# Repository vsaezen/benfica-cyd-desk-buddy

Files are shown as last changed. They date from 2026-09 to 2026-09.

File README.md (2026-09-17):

# Benfica CYD Desk Buddy

Proyecto de sobremesa para la pantalla táctil **Freenove FNK0114L / E32R32P de
3,2 pulgadas**. Reúne una interfaz inspirada en el Benfica, audio local,
información deportiva por Wi-Fi y una carcasa imprimible en 3D.

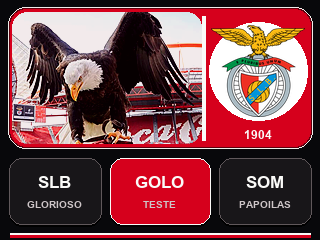
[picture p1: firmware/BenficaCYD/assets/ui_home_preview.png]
Interfaz principal


## Funciones

- Interfaz táctil de cuatro páginas con transiciones horizontales.
- Escudo, águila animada, `SLB GLORIOSO` y `PAPOILAS SALTITANTES`.
- Próximo partido, marcador, goleadores y clasificación portuguesa.
- Detección de partidos de Liga, Champions y otras competiciones.
- Himno con letra sincronizada.
- Reproducción autónoma desde microSD y altavoz de 8 ohmios.
- Configuración del Wi-Fi desde el móvil, sin guardar contraseñas en el código.
- Carcasa Rev. G para imprimir en una Bambu Lab A1 u otra impresora FDM.

## Antes de empezar

Este firmware está ajustado para el modelo exacto `FNK0114L_3P2` con ESP32
clásico, pantalla ST7789 de 240x320 y el amplificador integrado de esa placa. No
se debe cargar sin adaptar los pines en otras variantes de CYD.

Consulta primero:

1. [Instalación y copia en otra CYD](docs/INSTALACION.md)
2. [Esquema de conexiones](docs/CONEXIONES.md)
3. [Preparación de la microSD](sdcard/README.md)
4. [Impresión y montaje de la carcasa](hardware/enclosure/README.md)

## Instalación resumida

1. Formatea una microSD como FAT32 y copia en su raíz la carpeta
   `sdcard/Benfica`.
2. Instala ESP32 Arduino **2.0.11**, ArduinoJson **7.4.2**, ESP8266Audio
   **2.0.0** y la edición de `TFT_eSPI` suministrada por Freenove.
3. Comprueba que `TFT_eSPI` tiene seleccionado
   `FNK0114L_3P2_240x320_ST7789`. En `extras/TFT_eSPI_Setups` se conserva la
   configuración exacta utilizada en este proyecto.
4. Abre `firmware/BenficaCYD/BenficaCYD.ino` en Arduino IDE.
5. Selecciona `ESP32 Dev Module` y la partición
   `Huge APP (3MB No OTA/1MB SPIFFS)`.
6. Sube el programa por USB.
7. En el primer inicio, conéctate desde el móvil a `Benfica-CYD-Setup`, abre
   `http://192.168.4.1` y configura el Wi-Fi de casa.

## Estructura del repositorio

```text
firmware/BenficaCYD/     Sketch, imágenes integradas, fuente y herramientas
sdcard/Benfica/          Archivos que deben copiarse a la tarjeta FAT32
hardware/enclosure/      STL, proyectos 3MF, Blender y scripts de la carcasa
docs/                    Instalación detallada y conexiones
extras/                  Configuración de TFT_eSPI usada durante el desarrollo
```

## Estado de la información deportiva

La interfaz y el audio funcionan sin ordenador. Los últimos datos válidos se
guardan en el ESP32 y se muestran inmediatamente al encenderlo. La consulta
directa a los servidores públicos de ESPN no es una API oficial para este
proyecto y puede responder de manera intermitente, especialmente al descargar
la clasificación completa. El firmware conserva la caché anterior cuando una
consulta falla.

Una CYD recién programada no contiene esa caché: mostrará `A ATUALIZAR` hasta
que consiga una primera actualización válida. Para fabricar varias unidades y
garantizar actualizaciones estables se recomienda añadir en el futuro un
pequeño intermediario web con una respuesta JSON reducida.

## Licencias y marcas

El código y la documentación propios se publican bajo la licencia MIT incluida
en este repositorio. La fuente Graduate conserva su licencia OFL.

Este es un proyecto de aficionados, no oficial y no afiliado con Sport Lisboa e
Benfica, Freenove ni ESPN. Sus nombres, escudos, marcas, imágenes, canciones y
grabaciones pertenecen a sus respectivos titulares y no quedan cubiertos por la
licencia MIT. Antes de redistribuir o vender una unidad, sustituye cualquier
recurso para el que no tengas permiso de distribución.

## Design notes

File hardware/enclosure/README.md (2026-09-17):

# Carcasa Rev. G

Carcasa de sobremesa para la Freenove `FNK0114L_3P2` / `E32R32P`, un altavoz
redondo de 45x12 mm y una extensión USB-C trasera.

## Archivo recomendado

Para Bambu Lab A1 con boquilla de 0,4 mm abre:

```text
3mf/Benfica_CYD_Desk_Buddy_Freenove_3P2_REV_G_ALL_IN_ONE_A1_PLATE.3mf
```

No utilices `Auto arrange`: las piezas ya están colocadas en la cama. Revisa el
perfil antes de imprimir; se recomienda capa de 0,20 mm, cuatro perímetros y
20 % de relleno gyroid.

También están separados:

- `3mf/...REV_G_LCD_ALIGNED_EASY_CLOSE.3mf`: cuerpo y tapa.
- `3mf/...REV_G_PREMIUM_TRIMS.3mf`: embellecedores en segundo color.
- `stl/`: cinco piezas individuales para otros laminadores.
- `source/`: archivo Blender y generadores usados para modificar el diseño.

## Montaje

1. Introduce la placa desde la parte trasera y apóyala contra el marco frontal.
2. Alinea sus cuatro taladros con los soportes del cuerpo.
3. Fíjala con cuatro M3, arandelas y tuercas, apretando suavemente en cruz.
4. Comprueba pantalla y táctil antes de pegar el embellecedor frontal.
5. Conecta el altavoz, introduce la microSD y organiza el cable USB-C.
6. Cierra la tapa trasera y fíjala con cuatro M3.
7. Pega los embellecedores con cinta fina 3M o microgotas de cianoacrilato en
   gel, nunca sobre el cristal.

La abertura del frontal está ajustada de forma asimétrica a la unidad física
medida durante el prototipado. Las tolerancias pueden variar ligeramente entre
impresoras; limpia rebabas y elephant foot antes de forzar una pieza.

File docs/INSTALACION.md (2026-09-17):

# Instalación en una CYD nueva

## 1. Hardware compatible

La configuración verificada corresponde a:

- Freenove `FNK0114L_3P2` / `E32R32P`.
- ESP32 clásico de doble núcleo.
- Pantalla IPS táctil ST7789, 240x320 píxeles.
- Ranura microSD y amplificador analógico integrados.
- Altavoz pasivo de 8 ohmios y 1 W.

Si el modelo serigrafiado es distinto, no lo programes con estos pines sin
comparar antes el esquema del fabricante.

## 2. Preparar Arduino IDE

Configuración usada para compilar la versión probada:

| Componente | Versión/configuración |
|---|---|
| ESP32 Arduino | 2.0.11 |
| Placa | ESP32 Dev Module |
| Upload Speed | 460800 |
| Partition Scheme | Huge APP (3MB No OTA/1MB SPIFFS) |
| ArduinoJson | 7.4.2 |
| ESP8266Audio | 2.0.0 |
| TFT_eSPI Freenove | 2.5.43 |

Instala ArduinoJson y ESP8266Audio desde el gestor de bibliotecas. Para la
pantalla, instala la copia de TFT_eSPI incluida en el tutorial de Freenove para
esta placa. En `User_Setup_Select.h` debe quedar activa esta selección:

```cpp
#define FNK0114L_3P2_240x320_ST7789
```

Las demás selecciones Freenove del mismo bloque deben estar comentadas. El
archivo exacto de configuración usado está en:

```text
extras/TFT_eSPI_Setups/FNK0114L_3.2_240x320_ST7789.h
```

## 3. Preparar la microSD

1. Formatea la tarjeta como FAT32.
2. Copia la carpeta `sdcard/Benfica` completa a la raíz.
3. La ruta final debe ser `/Benfica/goal.mp3`, no
   `/sdcard/Benfica/goal.mp3` ni `/Benfica/Benfica/goal.mp3`.
4. Inserta la tarjeta con la placa apagada.

## 4. Subir el firmware

1. Conserva juntos `BenficaCYD.ino`, `BenficaAssets.h` y `BenficaFont.h` dentro
   de la carpeta `firmware/BenficaCYD`.
2. Abre `BenficaCYD.ino`.
3. Selecciona la placa, partición y puerto USB correctos.
4. Compila y sube.
5. No actives OTA: esta compilación utiliza una partición grande y las futuras
   actualizaciones se realizan por USB.

## 5. Configurar el Wi-Fi

En una placa nueva no existe ninguna contraseña guardada. Al arrancar creará la
red `Benfica-CYD-Setup`.

1. Conecta un móvil a esa red.
2. Abre `http://192.168.4.1` si el portal no aparece automáticamente.
3. Introduce la red Wi-Fi de 2,4 GHz y su contraseña.
4. La contraseña queda únicamente en la memoria privada de esa CYD y nunca se
   incorpora al sketch ni al repositorio.

## 6. Comprobación final

- La página inicial debe responder al tacto y deslizar con fluidez.
- La tarjeta debe reproducir los cuatro sonidos.
- La página 1904 debe mostrar la letra sincronizada.
- El dispositivo debe recuperar el Wi-Fi después de reproducir audio.
- La información deportiva puede tardar en la primera instalación si ESPN no
  entrega una respuesta completa. Esto no impide probar la interfaz y el audio.

Para repetir el montaje en otra unidad, vuelve a usar la misma carpeta, la misma
configuración de compilación y una copia independiente de la microSD.

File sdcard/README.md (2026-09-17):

# Tarjeta microSD

Formatea una microSD como FAT32 y copia la carpeta `Benfica` en su raíz:

```text
/Benfica/goal.mp3
/Benfica/glorioso.mp3
/Benfica/papoilas.mp3
/Benfica/hino.mp3
/Benfica/hino.lrc
```

Los nombres y las mayúsculas deben mantenerse exactamente. La letra y sus
tiempos también están integrados en el firmware, pero los MP3 sí son necesarios
para escuchar los sonidos sin ordenador.

Las grabaciones y canciones no quedan cubiertas por la licencia MIT del código.
Comprueba que tienes derecho a utilizarlas y redistribuirlas o sustitúyelas por
archivos propios conservando los mismos nombres.

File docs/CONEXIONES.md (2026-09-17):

# Esquema de conexiones

La pantalla, el táctil, la microSD y el amplificador ya forman parte de la
Freenove. La versión final no requiere una protoboard ni un cableado externo de
GPIO.

```text
                    USB-C / 5 V
                         │
                         ▼
              ┌────────────────────┐
              │ Freenove 3.2 CYD   │
 microSD ───► │ FNK0114L / E32R32P │
              │                    │
              │ salida SPK+  ──────┼────► altavoz 8 ohmios / 1 W
              │ salida SPK-  ──────┼────► altavoz 8 ohmios / 1 W
              └────────────────────┘
```

El altavoz se conecta a la **salida de dos pines del amplificador integrado**.
No debe conectarse directamente entre GPIO25 y masa: GPIO25 es la señal DAC que
alimenta internamente el amplificador, no una salida capaz de mover por sí sola
el altavoz.

## Pines usados internamente

| Función | GPIO |
|---|---:|
| Retroiluminación | 27 |
| Activación del amplificador | 4 |
| DAC de audio hacia el amplificador | 25 |
| SD SCK | 18 |
| SD MISO | 19 |
| SD MOSI | 23 |
| SD CS | 5 |

La propia pantalla usa un bus SPI diferente configurado en la biblioteca de
Freenove:

| Función | GPIO |
|---|---:|
| TFT MISO | 12 |
| TFT MOSI | 13 |
| TFT SCLK | 14 |
| TFT CS | 15 |
| TFT DC | 2 |
| Touch CS | 33 |

## Control háptico

El soporte DRV2605L está desactivado en esta versión. En esta revisión de la
placa, el conector I2C utiliza `IO32` para SDA y `IO25` para SCL, pero IO25
también alimenta el amplificador. Para evitar ruidos, bloqueos y pérdida de
fluidez se deja GPIO25 dedicado al audio.

No conectes el controlador háptico en la réplica final. El hueco de la carcasa
puede conservarse para futuras revisiones del hardware.

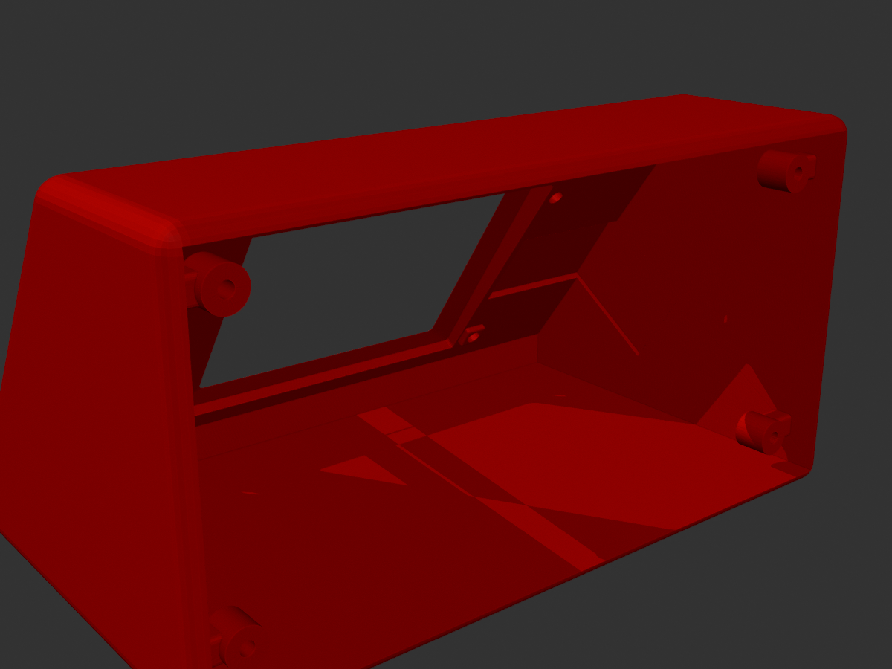
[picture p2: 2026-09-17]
hardware/enclosure/images/body_inside.png

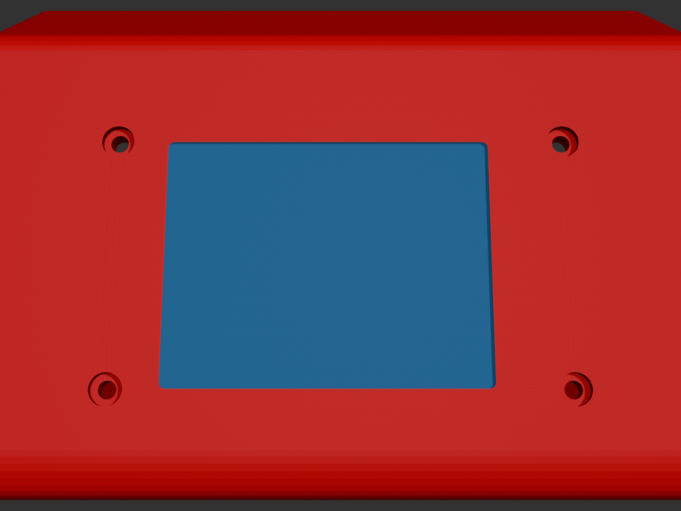
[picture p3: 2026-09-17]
hardware/enclosure/images/front_integral_ramp.png

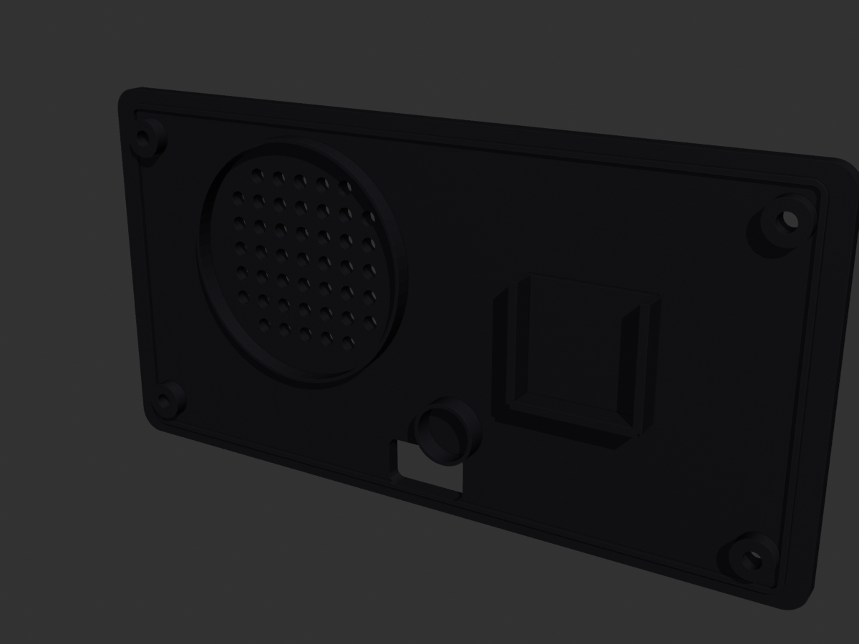
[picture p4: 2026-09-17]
hardware/enclosure/images/rear_inside.png

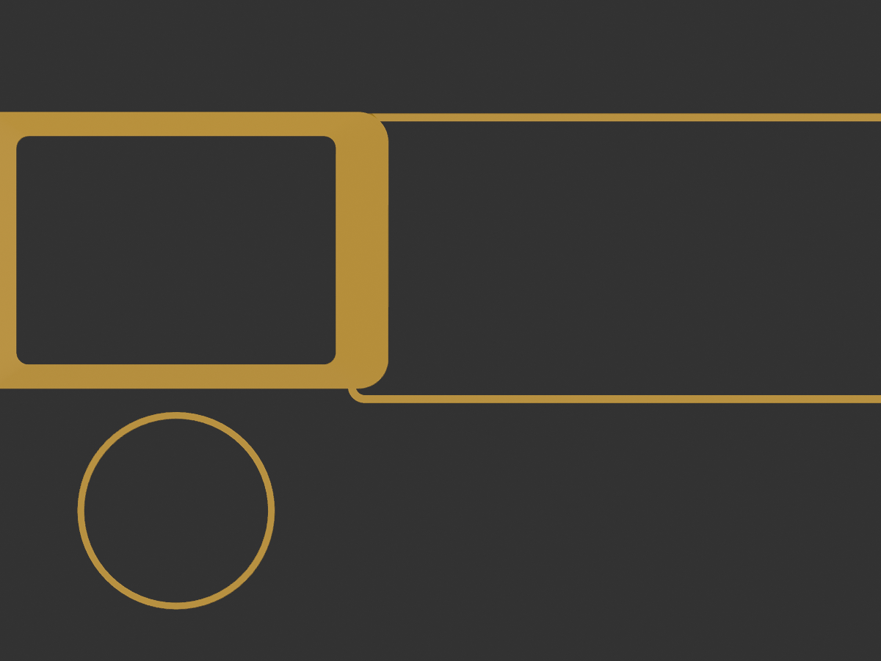
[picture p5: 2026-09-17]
hardware/enclosure/images/decorative_trims.png

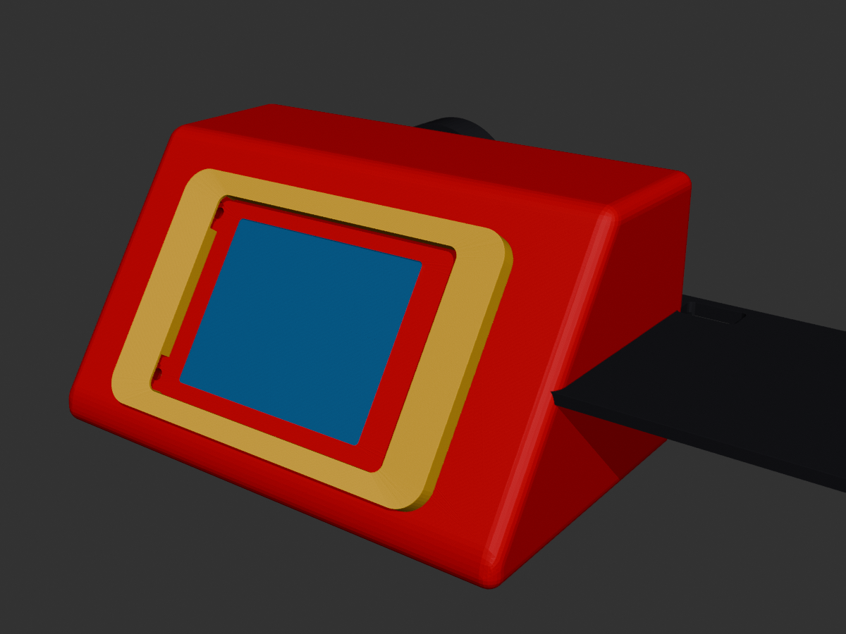
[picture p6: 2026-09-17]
hardware/enclosure/images/preview.png

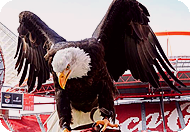
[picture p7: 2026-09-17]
firmware/BenficaCYD/assets/aguia_vitoria_190x132.png

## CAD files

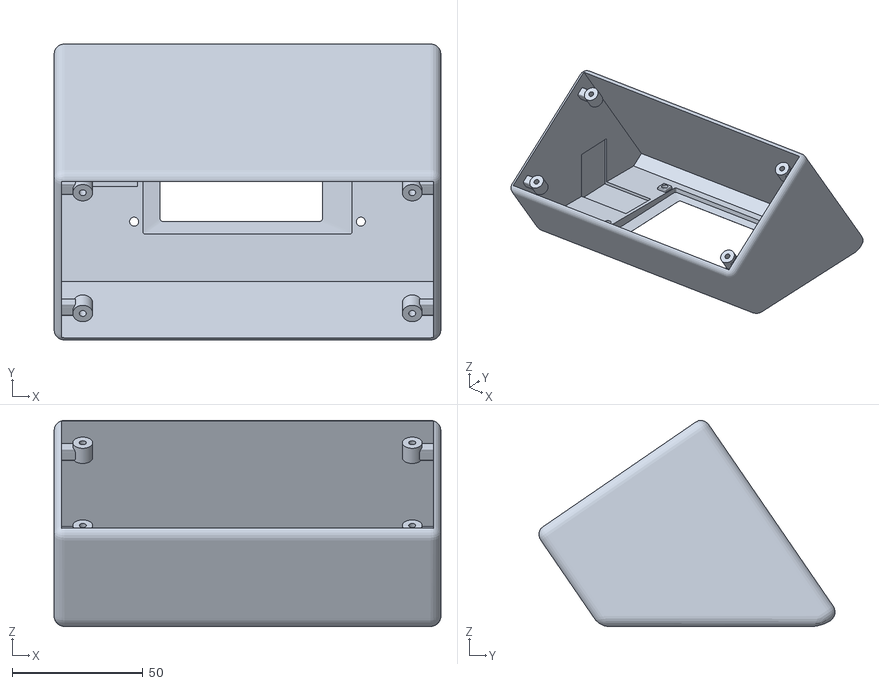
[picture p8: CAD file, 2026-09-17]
hardware/enclosure/stl/01_main_body_FRONT_DOWN_NO_SUPPORT.stl
148.0 x 113.2 x 78.8

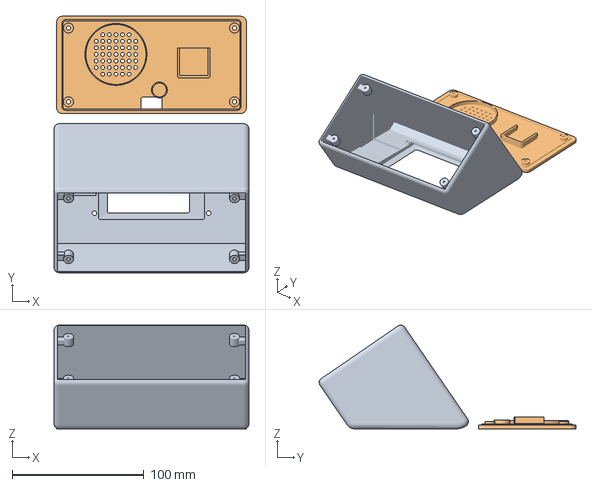
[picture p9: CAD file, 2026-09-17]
hardware/enclosure/3mf/Benfica_CYD_Desk_Buddy_Freenove_3P2_REV_G_LCD_ALIGNED_EASY_CLOSE.3mf
148.0 x 194.8 x 78.8 mm
Main body front-down
Rear panel

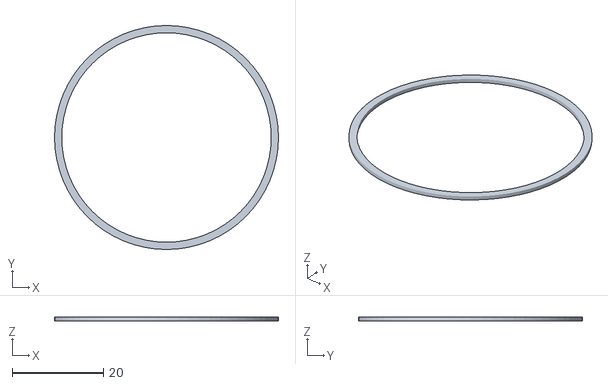
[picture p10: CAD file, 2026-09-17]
hardware/enclosure/stl/05_speaker_trim.stl
49.2 x 49.2 x 0.8

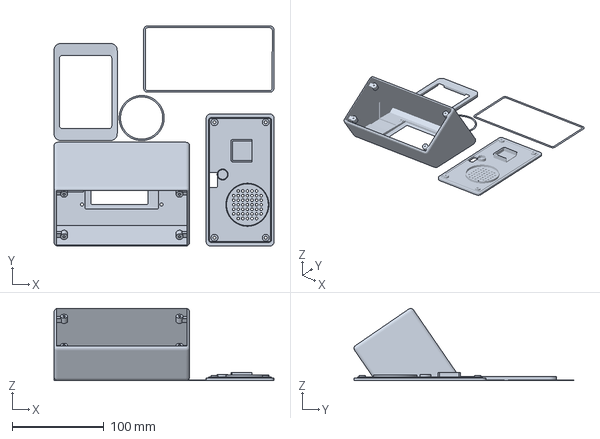
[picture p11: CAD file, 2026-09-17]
hardware/enclosure/3mf/Benfica_CYD_Desk_Buddy_Freenove_3P2_REV_G_ALL_IN_ONE_A1_PLATE.3mf
240.0 x 240.0 x 78.8 mm

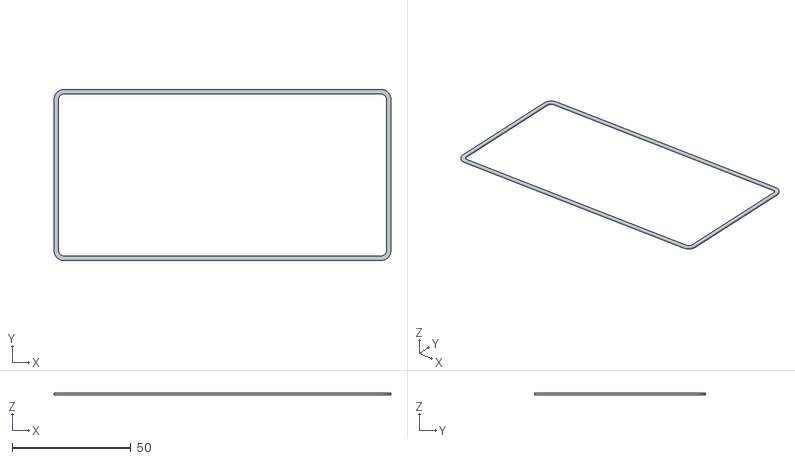
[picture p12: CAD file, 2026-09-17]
hardware/enclosure/stl/04_rear_seam_trim.stl
142.2 x 72.2 x 0.8

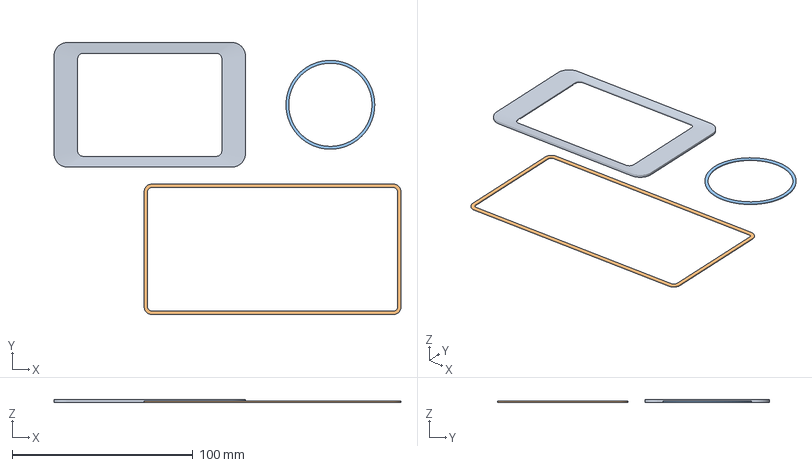
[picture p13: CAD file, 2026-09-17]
hardware/enclosure/3mf/Benfica_CYD_Desk_Buddy_Freenove_3P2_REV_G_PREMIUM_TRIMS.3mf
192.1 x 150.6 x 1.50 mm
Thick screen accent
Rear seam accent
Speaker accent trim

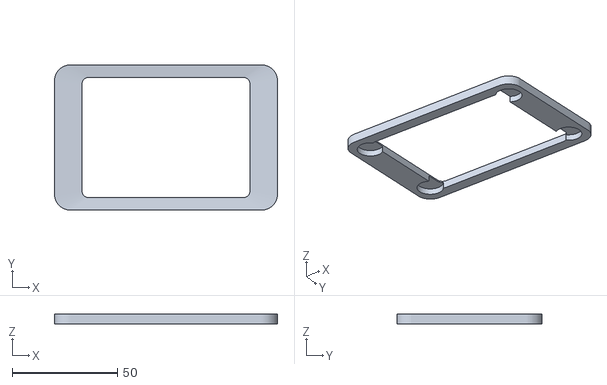
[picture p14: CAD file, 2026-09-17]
hardware/enclosure/stl/03_screen_trim.stl
106.0 x 69.0 x 4.60

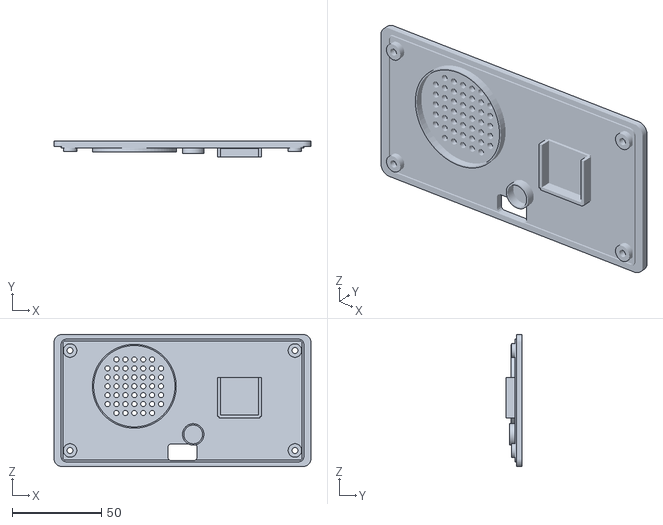
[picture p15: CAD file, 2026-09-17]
hardware/enclosure/stl/02_rear_panel.stl
144.0 x 9.00 x 74.0

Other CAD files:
hardware/enclosure/source/Benfica_CYD_Desk_Buddy.blend

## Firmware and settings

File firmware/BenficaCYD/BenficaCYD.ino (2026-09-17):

#include <Arduino.h>
#include <SPI.h>
#include <SD.h>
#include <Wire.h>
#include <TFT_eSPI.h>
#include <WiFi.h>
#include <WebServer.h>
#include <DNSServer.h>
#include <Preferences.h>
#include <ArduinoJson.h>
#include <time.h>
#include <esp_wifi.h>

#include <AudioFileSourceSD.h>
#include <AudioFileSourceID3.h>
#include <AudioGeneratorMP3.h>
#include <AudioOutputI2S.h>
#include <driver/i2s.h>

#include "BenficaAssets.h"
#include "BenficaFont.h"

// Freenove FNK0114L / E32R32P, 3.2", ST7789, 240x320.
// The interface is drawn in landscape at 320x240.
static constexpr uint8_t PIN_TFT_BACKLIGHT = 27;
static constexpr uint8_t PIN_AUDIO_ENABLE = 4;
static constexpr uint8_t PIN_SD_SCK = 18;
static constexpr uint8_t PIN_SD_MISO = 19;
static constexpr uint8_t PIN_SD_MOSI = 23;
static constexpr uint8_t PIN_SD_CS = 5;
static constexpr uint8_t PIN_HAPTIC_SDA = 32;
// On this exact FNK0114L_3P2 revision the I2C socket is silk-screened
// IO32(SDA) / IO25(SCL). GPIO25 is also the onboard amplifier input, so the
// firmware explicitly switches that shared pin between I2C and DAC use.
static constexpr uint8_t PIN_HAPTIC_SCL = 25;
static constexpr uint8_t HAPTIC_ADDRESS = 0x5A;

// The speaker is now installed: all MP3 files play directly from the microSD.
#define LOCAL_SPEAKER_ENABLED 1
// GPIO25 is shared by this board's I2C socket and analogue amplifier input.
// The haptic controller is deliberately disabled so GPIO25 remains dedicated
// to uninterrupted audio and touch/UI actions never wait on I2C timeouts.
#define HAPTIC_ENABLED 0
// Online refresh runs on CPU 0; the last successful data remains cached so
// the interface is immediate even when the server or Wi-Fi is unavailable.
#define ONLINE_REFRESH_ENABLED 1

static constexpr int SCREEN_W = 320;
static constexpr int SCREEN_H = 240;
static constexpr unsigned long HINO_DURATION_MS = 107000UL;

static const char *AUDIO_GOAL = "/Benfica/goal.mp3";
static const char *AUDIO_GLORIOSO = "/Benfica/glorioso.mp3";
static const char *AUDIO_PAPOILAS = "/Benfica/papoilas.mp3";
static const char *AUDIO_HINO = "/Benfica/hino.mp3";
static const char *LYRICS_HINO = "/Benfica/hino.lrc";
static const char *WIFI_AP_NAME = "Benfica-CYD-Setup";
static constexpr uint16_t WIFI_DNS_PORT = 53;
static constexpr unsigned long LIVE_REFRESH_MS = 5000UL;
static constexpr unsigned long NEAR_MATCH_REFRESH_MS = 60000UL;
static constexpr unsigned long IDLE_EVENT_REFRESH_MS = 60000UL;
static constexpr unsigned long SCHEDULE_REFRESH_MS = 10800000UL;
static constexpr unsigned long TABLE_REFRESH_MS = 21600000UL;

TFT_eSPI tft = TFT_eSPI();
TFT_eSprite canvas = TFT_eSprite(&tft);
SPIClass sdSpi(VSPI);
Preferences preferences;
bool preferencesReady = false;
DNSServer dnsServer;
WebServer setupServer(80);
SemaphoreHandle_t dataMutex = nullptr;
SemaphoreHandle_t networkAudioMutex = nullptr;

// ESP8266Audio normally removes and recreates the I2S driver for every song.
// Keeping it installed makes playback start instantly, avoids DMA allocation
// failures while Wi-Fi is active, and lets network updates continue normally.
class PersistentDacOutput : public AudioOutputI2S {
 public:
  PersistentDacOutput(int port, int buffers)
      : AudioOutputI2S(port, AudioOutputI2S::INTERNAL_DAC, buffers) {}

  bool stop() override {
    if (i2sOn) i2s_zero_dma_buffer((i2s_port_t)portNo);
    return true;
  }
};

// ArduinoJson reads a Stream one byte at a time. With a long standings reply,
// a continuously available TCP buffer can keep CPU 0 busy long enough for the
// idle-task watchdog to fire. Yielding briefly every few hundred bytes keeps
// Wi-Fi and the watchdog healthy without slowing the visible interface.
class CooperativeStream : public Stream {
 public:
  explicit CooperativeStream(Stream &source) : source_(source) {}

  int available() override { return source_.available(); }
  int peek() override {
    unsigned long started = millis();
    int value = source_.peek();
    while (value < 0 && millis() - started < source_.getTimeout()) {
      vTaskDelay(pdMS_TO_TICKS(1));
      value = source_.peek();
    }
    return value;
  }
  void flush() override { source_.flush(); }
  size_t write(uint8_t value) override { return source_.write(value); }

  int read() override {
    int value = source_.read();
    // TCP data arrives in packets. An immediate -1 only means that the next
    // packet is not in the receive buffer yet, not that the JSON document has
    // ended. Wait up to the socket timeout so ArduinoJson never mistakes a
    // short network pause for end-of-file.
    unsigned long started = millis();
    while (value < 0 && millis() - started < source_.getTimeout()) {
      vTaskDelay(pdMS_TO_TICKS(1));
      value = source_.read();
    }
    cooperate(value >= 0 ? 1 : 0);
    return value;
  }

  size_t readBytes(char *buffer, size_t length) override {
    size_t count = source_.readBytes(buffer, length);
    cooperate(count);
    return count;
  }

 private:
  void cooperate(size_t count) {
    bytesSinceYield_ += count;
    if (bytesSinceYield_ >= 256 || count == 0) {
      bytesSinceYield_ = 0;
      vTaskDelay(pdMS_TO_TICKS(1));
    }
  }

  Stream &source_;
  size_t bytesSinceYield_ = 0;
};

enum Page : uint8_t {
  PAGE_HOME,
  PAGE_MATCH,
  PAGE_TABLE,
  PAGE_HYMN,
  PAGE_COUNT
};

enum Overlay : uint8_t {
  OVERLAY_NONE,
  OVERLAY_GLORIOSO,
  OVERLAY_PAPOILAS,
  OVERLAY_GOAL
};

// Read only a short value after a known JSON marker. This avoids retaining or
// deserializing the server's 60-290 KB documents on a non-PSRAM ESP32.
static bool readJsonText(Stream &stream, String &value, size_t maximumBytes) {
  value = "";
  bool escaped = false;
  while (value.length() < maximumBytes) {
    int next = stream.read();
    if (next < 0) return false;
    char character = (char)next;
    if (escaped) {
      value += character;
      escaped = false;
    } else if (character == '\\') {
      escaped = true;
    } else if (character == '"') {
      return true;
    } else {
      value += character;
    }
  }
  return false;
}

static bool findJsonText(Stream &stream, const char *marker, String &value,
                         size_t maximumBytes) {
  return stream.find(marker) && readJsonText(stream, value, maximumBytes);
}

static bool readJsonInteger(Stream &stream, int &value) {
  String number;
  int next = stream.read();
  while (next == ' ' || next == '\r' || next == '\n' || next == '\t') {
    next = stream.read();
  }
  while ((next >= '0' && next <= '9') || next == '-' || next == '.') {
    number += (char)next;
    next = stream.read();
  }
  if (!number.length()) return false;
  value = number.toInt();
  return true;
}

AudioFileSourceSD *audioFile = nullptr;
AudioFileSourceID3 *audioId3 = nullptr;
AudioOutputI2S *audioOutput = nullptr;
AudioGeneratorMP3 *audioDecoder = nullptr;
alignas(8) uint8_t audioDecoderMemory[AudioGeneratorMP3::preAllocSize()];

uint16_t C_BG;
uint16_t C_BG_2;
uint16_t C_SURFACE;
uint16_t C_SURFACE_2;
uint16_t C_RED;
uint16_t C_RED_DARK;
uint16_t C_GOLD;
uint16_t C_WHITE;
uint16_t C_MUTED;
uint16_t C_BORDER;
uint16_t C_GREEN;
uint16_t C_BLACK;

Page currentPage = PAGE_HOME;
Overlay overlay = OVERLAY_NONE;

bool sdReady = false;
bool hapticReady = false;
bool canvasReady = false;
bool audioPlaying = false;
bool audioDacInstalled = false;
bool remoteAudioPlaying = false;
bool audioOwnsNetworkMutex = false;
bool matchActive = false;
bool goalIsDemo = false;
bool hymnPlaying = false;
volatile bool wifiReady = false;
volatile bool pendingNetworkGoal = false;
volatile bool forceNetworkRefresh = false;
volatile uint8_t networkStage = 0;
volatile uint8_t lastWifiDisconnectReason = 0;
TaskHandle_t networkTaskHandle = nullptr;
static constexpr uint32_t NETWORK_STACK_BYTES = 8192;
StaticTask_t networkTaskControl;
StackType_t networkTaskStack[NETWORK_STACK_BYTES / sizeof(StackType_t)];
bool championsMatch = false;
bool nextIsChampions = false;
String competitionText = "LIGA PORTUGUESA";
String activeEventId;
String activeLeague;
time_t activeEventEpoch = 0;
int lastNetworkBenficaScore = -1;

String scoreText = "SLB 0-0 RIVAL";
String scorerText = "A AGUARDAR";
String goalHistory;
String nextOpponent = "A ATUALIZAR";
String nextDate = "PROXIMO JOGO";
String nextTimePortugal = "--:-- PT";
String nextTimeSpain = "--:-- ES";
String wifiSsid;
String wifiPassword;
String serialLine;
File uploadFile;
String uploadPath;
uint32_t uploadExpected = 0;
uint32_t uploadReceived = 0;
volatile bool uploadActive = false;
volatile bool transferSession = false;

static constexpr uint8_t MAX_TABLE_TEAMS = 18;
String tableTeam[MAX_TABLE_TEAMS];
uint8_t tablePoints[MAX_TABLE_TEAMS];
uint8_t tableCount = 0;

struct LyricLine {
  uint32_t atMs;
  String text;
};

struct BuiltinLyricLine {
  uint32_t atMs;
  const char *text;
};

// Timed against the exact 1:47 MP3 stored as /Benfica/hino.mp3. The words were
// supplied directly by the user; onset timings were aligned to the recording.
static const BuiltinLyricLine BUILTIN_LYRICS[] = {
  { 7860, "Sou do Benfica" },
  { 13300, "E isso me envaidece" },
  { 17940, "Tenho a genica" },
  { 23300, "Que a qualquer engrandece" },
  { 30500, "Sou de um clube lutador" },
  { 38660, "Que na luta, com fervor" },
  { 46980, "Nunca encontrou rival" },
  { 54180, "Neste nosso Portugal" },
  { 61920, "Ser Benfiquista" },
  { 65880, "É ter na alma a chama imensa" },
  { 71180, "Que nos conquista" },
  { 73700, "E leva à palma a luz intensa" },
  { 77740, "Do Sol que lá no céu," },
  { 80500, "risonho, vem beijar" },
  { 83500, "Com orgulho muito seu" },
  { 87140, "As camisolas berrantes" },
  { 90680, "Que nos campos a vibrar" },
  { 95100, "São papoilas saltitantes" },
};

static constexpr uint8_t MAX_LYRIC_LINES = 48;
LyricLine lyrics[MAX_LYRIC_LINES];
uint8_t lyricCount = 0;

bool touchWasDown = false;
int touchStartX = 0;
int touchStartY = 0;
int touchLastX = 0;
int touchLastY = 0;

bool transitionActive = false;
Page transitionFrom = PAGE_HOME;
Page transitionTo = PAGE_HOME;
int transitionDirection = 1;
unsigned long transitionStarted = 0;

unsigned long lastTouchPoll = 0;
unsigned long lastTouchEvent = 0;
unsigned long lastFrame = 0;
unsigned long overlayStarted = 0;
unsigned long remoteAudioUntil = 0;
unsigned long hymnStartedAt = 0;

// DRV2605L registers used by the built-in ERM waveform player.
static constexpr uint8_t DRV_REG_MODE = 0x01;
static constexpr uint8_t DRV_REG_RTP = 0x02;
static constexpr uint8_t DRV_REG_LIBRARY = 0x03;
static constexpr uint8_t DRV_REG_WAVESEQ1 = 0x04;
static constexpr uint8_t DRV_REG_GO = 0x0C;
static constexpr uint8_t DRV_REG_OVERDRIVE = 0x0D;
static constexpr uint8_t DRV_REG_SUSTAIN_POS = 0x0E;
static constexpr uint8_t DRV_REG_SUSTAIN_NEG = 0x0F;
static constexpr uint8_t DRV_REG_BRAKE = 0x10;
static constexpr uint8_t DRV_REG_AUDIO_MAX = 0x13;
static constexpr uint8_t DRV_REG_FEEDBACK = 0x1A;
static constexpr uint8_t DRV_REG_CONTROL3 = 0x1D;

static void selectHapticBus() {
#if HAPTIC_ENABLED
#if LOCAL_SPEAKER_ENABLED
  if (audioDacInstalled) {
    i2s_zero_dma_buffer(I2S_NUM_0);
    i2s_set_dac_mode(I2S_DAC_CHANNEL_DISABLE);
  }
#endif
  Wire.end();
  Wire.begin(PIN_HAPTIC_SDA, PIN_HAPTIC_SCL, 100000);
  Wire.setTimeOut(40);
#endif
}

static void selectAudioDac() {
#if LOCAL_SPEAKER_ENABLED
#if HAPTIC_ENABLED
  Wire.end();
  delay(1);
#endif
  if (audioDacInstalled) {
    i2s_set_pin(I2S_NUM_0, nullptr);
    i2s_set_dac_mode(I2S_DAC_CHANNEL_BOTH_EN);
    i2s_zero_dma_buffer(I2S_NUM_0);
  }
#endif
}

static bool hapticWriteRegister(uint8_t reg, uint8_t value) {
  Wire.beginTransmission(HAPTIC_ADDRESS);
  Wire.write(reg);
  Wire.write(value);
  return Wire.endTransmission() == 0;
}

static bool hapticReadRegister(uint8_t reg, uint8_t &value) {
  Wire.beginTransmission(HAPTIC_ADDRESS);
  Wire.write(reg);
  if (Wire.endTransmission(false) != 0) return false;
  if (Wire.requestFrom(HAPTIC_ADDRESS, (uint8_t)1) != 1) return false;
  value = Wire.read();
  return true;
}

static bool initHaptics() {
#if !HAPTIC_ENABLED
  Serial.println("HAPTIC|DISABLED");
  return false;
#else
  Wire.begin(PIN_HAPTIC_SDA, PIN_HAPTIC_SCL, 100000);
  Wire.setTimeOut(40);
  delay(8);

  Wire.beginTransmission(HAPTIC_ADDRESS);
  if (Wire.endTransmission() != 0) {
    Serial.println("HAPTIC|MISSING|0x5A");
    return false;
  }

  uint8_t feedback = 0;
  uint8_t control3 = 0;
  bool ok = hapticReadRegister(DRV_REG_FEEDBACK, feedback) &&
            hapticReadRegister(DRV_REG_CONTROL3, control3);
  ok = hapticWriteRegister(DRV_REG_MODE, 0x00) && ok;
  ok = hapticWriteRegister(DRV_REG_RTP, 0x00) && ok;
  ok = hapticWriteRegister(DRV_REG_LIBRARY, 0x01) && ok;
  ok = hapticWriteRegister(DRV_REG_WAVESEQ1, 0x01) && ok;
  ok = hapticWriteRegister(DRV_REG_WAVESEQ1 + 1, 0x00) && ok;
  ok = hapticWriteRegister(DRV_REG_OVERDRIVE, 0x00) && ok;
  ok = hapticWriteRegister(DRV_REG_SUSTAIN_POS, 0x00) && ok;
  ok = hapticWriteRegister(DRV_REG_SUSTAIN_NEG, 0x00) && ok;
  ok = hapticWriteRegister(DRV_REG_BRAKE, 0x00) && ok;
  ok = hapticWriteRegister(DRV_REG_AUDIO_MAX, 0x64) && ok;
  ok = hapticWriteRegister(DRV_REG_FEEDBACK, feedback & 0x7F) && ok;
  ok = hapticWriteRegister(DRV_REG_CONTROL3, control3 | 0x20) && ok;
  Serial.printf("HAPTIC|%s|0x5A\n", ok ? "READY" : "INIT_ERROR");
  return ok;
#endif
}

static void playHapticSequence(const uint8_t *sequence, size_t count) {
  if (!hapticReady) return;
  hapticWriteRegister(DRV_REG_GO, 0x00);
  for (size_t slot = 0; slot < 8; ++slot) {
    hapticWriteRegister(DRV_REG_WAVESEQ1 + slot,
                        slot < count ? sequence[slot] : 0x00);
  }
  hapticWriteRegister(DRV_REG_GO, 0x01);
}

static void hapticSoftTap() {
  const uint8_t sequence[] = {7};
  playHapticSequence(sequence, sizeof(sequence));
}

static void hapticConfirm() {
  const uint8_t sequence[] = {1};
  playHapticSequence(sequence, sizeof(sequence));
}

static void hapticGoal() {
  const uint8_t sequence[] = {1, 0x84, 10, 0x84, 14};
  playHapticSequence(sequence, sizeof(sequence));
}

static uint16_t mix565(uint16_t a, uint16_t b, uint8_t amount) {
  uint8_t ar = (a >> 11) & 0x1F;
  uint8_t ag = (a >> 5) & 0x3F;
  uint8_t ab = a & 0x1F;
  uint8_t br = (b >> 11) & 0x1F;
  uint8_t bg = (b >> 5) & 0x3F;
  uint8_t bb = b & 0x1F;
  uint8_t rr = ar + ((int16_t)(br - ar) * amount) / 255;
  uint8_t rg = ag + ((int16_t)(bg - ag) * amount) / 255;
  uint8_t rb = ab + ((int16_t)(bb - ab) * amount) / 255;
  return (rr << 11) | (rg << 5) | rb;
}

static void fillGradient(int x, int y, int w, int h,
                         uint16_t top, uint16_t bottom) {
  for (int row = 0; row < h; ++row) {
    uint8_t amount = h <= 1 ? 255 : (uint32_t)row * 255 / (h - 1);
    canvas.drawFastHLine(x, y + row, w, mix565(top, bottom, amount));
  }
}

static void centeredText(const String &text, int x, int y,
                         const GFXfont *font, uint16_t color) {
  canvas.setFreeFont(font);
  canvas.setTextColor(color);
  canvas.setTextDatum(MC_DATUM);
  canvas.drawString(text, x, y);
}

static void leftText(const String &text, int x, int y,
                     const GFXfont *font, uint16_t color) {
  canvas.setFreeFont(font);
  canvas.setTextColor(color);
  canvas.setTextDatum(ML_DATUM);
  canvas.drawString(text, x, y);
}

static void smallText(const String &text, int x, int y, uint16_t color,
                      uint8_t datum = ML_DATUM) {
  canvas.setFreeFont(nullptr);
  canvas.setTextFont(1);
  canvas.setTextSize(1);
  canvas.setTextColor(color);
  canvas.setTextDatum(datum);
  canvas.drawString(text, x, y);
}

static String shortened(const String &text, uint8_t length) {
  if (text.length() <= length) return text;
  if (length < 4) return text.substring(0, length);
  return text.substring(0, length - 3) + "...";
}

static void panel(int x, int y, int w, int h, int radius,
                  uint16_t fill, bool border = true) {
  canvas.fillRoundRect(x + 2, y + 3, w, h, radius, C_BLACK);
  canvas.fillRoundRect(x, y, w, h, radius, fill);
  if (border) canvas.drawRoundRect(x, y, w, h, radius, C_BORDER);
}

static void pushTransparentAsset(int x, int y, int w, int h,
                                 const uint16_t *asset) {
  // Copy horizontal opaque runs instead of calling drawPixel for every pixel.
  // On the 8-bit framebuffer this is several times faster, especially for the
  // moving eagle and the crest on the home screen.
  for (int py = 0; py < h; ++py) {
    int dy = y + py;
    if (dy < 0 || dy >= SCREEN_H) continue;
    int px = 0;
    while (px < w) {
      while (px < w && pgm_read_word(asset + py * w + px) == BENFICA_IMAGE_KEY) ++px;
      int runStart = px;
      while (px < w && pgm_read_word(asset + py * w + px) != BENFICA_IMAGE_KEY) ++px;
      int runLength = px - runStart;
      int dx = x + runStart;
      if (runLength > 0 && dx < SCREEN_W && dx + runLength > 0) {
        int cropLeft = max(0, -dx);
        int cropRight = max(0, dx + runLength - SCREEN_W);
        int visible = runLength - cropLeft - cropRight;
        if (visible > 0) {
          canvas.pushImage(dx + cropLeft, dy, visible, 1,
                           asset + py * w + runStart + cropLeft);
        }
      }
    }
  }
}

static void drawTopBar(const String &section, int ox) {
  canvas.fillRect(ox, 0, SCREEN_W, 34, C_BLACK);
  canvas.fillRect(ox, 0, 6, 34, C_RED);
  leftText("SL BENFICA", ox + 16, 13, &Graduate18, C_WHITE);
  canvas.fillCircle(ox + 302, 17, 3, wifiReady ? C_GREEN : C_RED);
  smallText(section, ox + 292, 18, C_MUTED, MR_DATUM);
}

static void drawChampionsBadge(int cx, int cy, uint16_t color) {
  // Compact monochrome star-ball mark for Champions fixtures.
  const float step = 0.78539816f;
  int px[8];
  int py[8];
  for (uint8_t i = 0; i < 8; ++i) {
    float angle = -1.5707963f + i * step;
    px[i] = cx + (int)(14.0f * cosf(angle));
    py[i] = cy + (int)(14.0f * sinf(angle));
  }
  for (uint8_t i = 0; i < 8; ++i) {
    uint8_t next = (i + 1) & 7;
    canvas.drawLine(px[i], py[i], px[next], py[next], color);
    canvas.fillTriangle(px[i], py[i],
                        cx + (px[i] - cx) / 2 - (py[i] - cy) / 5,
                        cy + (py[i] - cy) / 2 + (px[i] - cx) / 5,
                        cx + (px[i] - cx) / 2 + (py[i] - cy) / 5,
                        cy + (py[i] - cy) / 2 - (px[i] - cx) / 5,
                        color);
  }
  canvas.drawCircle(cx, cy, 7, color);
}

static void drawPageDots(Page active, int ox) {
  for (uint8_t i = 0; i < PAGE_COUNT; ++i) {
    int x = ox + 142 + i * 12;
    if (i == active) canvas.fillRoundRect(x - 3, 229, 8, 5, 2, C_RED);
    else canvas.fillCircle(x, 231, 2, C_MUTED);
  }
}

static void drawButton(int x, int y, int w, int h, const String &label,
                       bool primary) {
  uint16_t fill = primary ? C_RED : C_SURFACE_2;
  canvas.fillRoundRect(x + 2, y + 3, w, h, 10, C_BLACK);
  canvas.fillRoundRect(x, y, w, h, 10, fill);
  canvas.drawRoundRect(x, y, w, h, 10, primary ? C_WHITE : C_BORDER);
  centeredText(label, x + w / 2, y + h / 2 + 1, &Graduate18, C_WHITE);
}

static const uint16_t *eagleFrame(uint8_t frame) {
  switch (frame & 3) {
    case 0: return EAGLE_FLIGHT_0;
    case 1: return EAGLE_FLIGHT_1;
    case 2: return EAGLE_FLIGHT_2;
    default: return EAGLE_FLIGHT_3;
  }
}

static void drawHome(int ox) {
  fillGradient(ox, 0, SCREEN_W, SCREEN_H, C_BG_2, C_BLACK);
  drawTopBar("INICIO", ox);

  // Restrained hero card: the crest remains optically centred while the eagle
  // moves above it on a separate visual plane.
  panel(ox + 10, 40, 300, 130, 18, C_RED_DARK, true);
  canvas.fillRoundRect(ox + 13, 43, 294, 124, 16, C_RED);
  canvas.fillCircle(ox + 160, 104, 51, C_WHITE);
  pushTransparentAsset(ox + 112, 56, BENFICA_CREST_WIDTH,
                       BENFICA_CREST_HEIGHT, BENFICA_CREST);

  unsigned long flight = millis() % 6600UL;
  int eagleX = ox - 104 + (int)((uint32_t)flight * 440UL / 6600UL);
  int eagleY = 31 + (int)(7.0f * sinf(flight * 0.0045f));
  uint8_t frame = (millis() / 145UL) & 3;
  pushTransparentAsset(eagleX, eagleY, EAGLE_FLIGHT_0_WIDTH,
                       EAGLE_FLIGHT_0_HEIGHT, eagleFrame(frame));

  drawButton(ox + 10, 180, 145, 40, "SLB GLORIOSO", false);
  drawButton(ox + 165, 180, 145, 40, "PAPOILAS", true);
  drawPageDots(PAGE_HOME, ox);
}

static String historyEntry(uint8_t wanted) {
  int start = 0;
  for (uint8_t index = 0; index <= wanted; ++index) {
    int end = goalHistory.indexOf(';', start);
    if (index == wanted) {
      if (end < 0) return goalHistory.substring(start);
      return goalHistory.substring(start, end);
    }
    if (end < 0) return "";
    start = end + 1;
  }
  return "";
}
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
void loop() {
  // During a USB-to-SD transfer, give the serial receiver and filesystem
  // exclusive attention. Touch, drawing, audio and web requests stay paused.
  if (transferSession || uploadActive) {
    pollSerial();
    delay(1);
    return;
  }
  serviceAudio();
  if (pendingNetworkGoal) {
    pendingNetworkGoal = false;
    currentPage = PAGE_MATCH;
    startGoal(false);
  }
  pollSerial();
  serviceAudio();
  pollTouch();
  serviceAudio();

  unsigned long now = millis();
  unsigned long interval = 83;
  if (transitionActive || overlay == OVERLAY_GOAL) interval = 48;
  if (currentPage == PAGE_MATCH && overlay == OVERLAY_NONE) interval = 180;
  if (currentPage == PAGE_TABLE && overlay == OVERLAY_NONE) interval = 250;
  if (now - lastFrame >= interval && canvasReady) {
    lastFrame = now;
    renderFrame();
  }
  serviceAudio();
  delay(1);
}

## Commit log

2026-09-17 Add printable enclosure files
    [01_main_body_FRONT_DOWN_NO_SUPPORT.stl, 02_rear_panel.stl, 03_screen_trim.stl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]
2026-09-17 Add enclosure design sources
    [Benfica_CYD_Desk_Buddy.blend]
2026-09-17 Add front assembly preview
2026-09-17 Add enclosure preview
